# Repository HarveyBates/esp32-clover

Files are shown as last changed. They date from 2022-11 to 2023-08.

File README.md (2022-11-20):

# esp32-clover
ESP32 Clover development board.

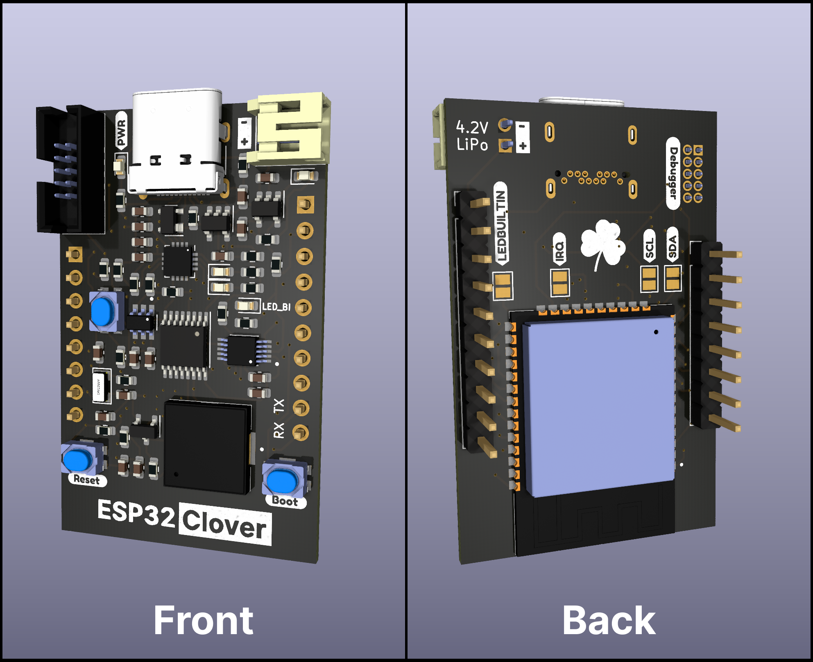
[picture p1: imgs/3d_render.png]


## Features
- [x] USB-C connector
- [x] Debugger connector for ESP-Prog
- [x] Piezo buzzer (audible feedback)
- [x] Additional ADC (2 inputs, 12-bit)
- [x] Additional IO (2 inputs/outputs with interrupt)
- [x] Additional DAC (1 channel, 8-bit)
- [x] Battery charger (single cell LiPo)
- [x] Built-in LED
- [x] Programmable button
- [x] Breadboard friendly
- [x] Small footprint (29.2 mm x 46.5 mm)

## Schematic
The devices schematic can be found [here](https://github.com/HarveyBates/esp32-clover/blob/master/electronics/esp32-clover/schematics/esp32-clover.pdf)

## Licence
This project is under the GNU LESSER GENERAL PUBLIC LICENSE as found in the LICENCE file.

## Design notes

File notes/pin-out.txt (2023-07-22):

GPIO - 8 (TCA9534 - 0 to 7)
PWR - 5 (USB, 3.3V, Bat, RESET, GND)
ADC - 5 (ADC124S... 0 to 3 GND)
DAC - 5 (MCP4728 0 to 3, GND)
MISC - 10 (TX, RX, SDA, SCL, SCK, MISO, MOSI, GPIO21, GPIO17, GPIO27)
	As two 5 Pins

1 x 8 pin
5 * 5 pin

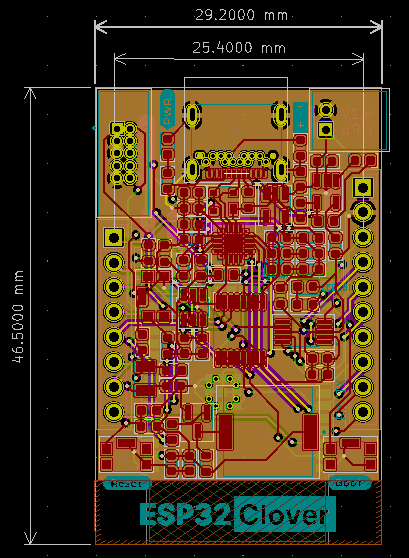
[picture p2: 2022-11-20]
imgs/pcb_layout.png

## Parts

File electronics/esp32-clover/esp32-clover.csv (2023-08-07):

Source: | /Users/hbates/projects/esp32-clover/electronics/esp32-clover/esp32-clover.kicad_sch
Date: | 2023 August 04, Friday 09:54:28
Tool: | Eeschema 7.0.6-0
Generator: | /Applications/KiCad/KiCad.app/Contents/SharedSupport/plugins/bom_csv_grouped_by_value.py
Component Count: | 136
Collated Components:
Item | Qty | Reference(s) | Value | LibPart | Footprint | Datasheet | DNP | Arrow Part Number | Arrow Price/Stock | Color | DESCRIPTION | DIGI-KEY_PART_NUMBER | DIGI-KEY_PURCHASE_URL | Height | MANUFACTURER | MAXIMUM_PACKAGE_HEIGHT | MP | Manufacturer_Name | Manufacturer_Part_Number | Mouser Part Number | Mouser Price/Stock | PACKAGE | PARTREV | Part | SNAPEDA_PN | STANDARD | Supplier
1 | 1 | BT1 | BCAAPC | BCAAPC:BCAAPC | BAT_BCAAPC |  |  |  |  |  |  |  |  |  | MPD | 13.25mm |  |  |  |  |  |  | 05/30/19 |  |  | Manufacturer Recommendation
2 | 4 | C1, C8, C29, C30 | 1uF | Device:C | Capacitor_SMD:C_0603_1608Metric | ~
3 | 5 | C2, C9, C11, C14, C15 | 0.1uF | Device:C | Capacitor_SMD:C_0603_1608Metric | ~
4 | 1 | C3 | 22uF | Device:C | Capacitor_SMD:C_0603_1608Metric | ~
5 | 4 | C4, C5, C6, C7 | 12pF | Device:C | Capacitor_SMD:C_0603_1608Metric | ~
6 | 1 | C10 | 10uF | Device:C | Capacitor_SMD:C_0603_1608Metric | ~
7 | 5 | C12, C13, C16, C18, C20 | 4.7uF | Device:C | Capacitor_SMD:C_0603_1608Metric | ~
8 | 1 | C17 | 2.2uF | Device:C |  | ~
9 | 3 | C19, C23, C24 | 1uF | Device:C |  | ~
10 | 2 | C21, C22 | 0.1uF | Device:C |  | ~
11 | 1 | C25 | 10uF | Device:C |  | ~
12 | 1 | C26 | 4.7uF | Device:C |  | ~
13 | 1 | C27 | 22pF | Device:C |  | ~
14 | 1 | C28 | TBD | Device:C | Capacitor_SMD:C_0603_1608Metric | ~ | DNP
15 | 4 | C31, C33, C34, C35 | 22uF | Device:C |  | ~
16 | 1 | C32 | 10nF | Device:C |  | ~
17 | 3 | D1, D2, D3 | SP4020-01FTG | SP4020-01FTG:SP4020-01FTG | SOD2613X114N | https://www.littelfuse.com/~/media/electronics/datasheets/tvs_diode_arrays/littelfuse_tvs_diode_array_sp4020_datasheet.pdf.pdf |  | SP4020-01FTG | https://www.arrow.com/en/products/sp4020-01ftg/littelfuse?region=nac |  |  |  |  | 1.14 |  |  |  | LITTELFUSE | SP4020-01FTG | 576-SP4020-01FTG | https://www.mouser.co.uk/ProductDetail/Littelfuse/SP4020-01FTG?qs=eIdvKxokjW4Yi6Ov7kZjPg%3D%3D
18 | 5 | D4, D5, D7, D8, D9 | LED | Device:LED | LED_SMD:LED_0603_1608Metric | ~ |  |  |  | Green
19 | 1 | D6 | SP0503BAHT | Power_Protection:SP0503BAHT | Package_TO_SOT_SMD:SOT-143 | http://www.littelfuse.com/~/media/files/littelfuse/technical%20resources/documents/data%20sheets/sp05xxba.pdf |  |  |  |  |  |  |  |  |  |  |  |  |  |  |  |  |  |  |  |  | https://au.element14.com/littelfuse/sp0503bahtg/esd-protection-device-5-5v-sot/dp/1827633?st=SP0503BAHTG
20 | 2 | D10, D11 | LED | Device:LED |  | ~
21 | 2 | D12, D13 | SK34A | diodes:SK34A | diodes:SK34A |  |  |  |  |  |  |  |  |  | Taiwan Semiconductor | 2.5 mm |  |  |  |  |  |  | O2102 |  |  | IPC-7351B
22 | 1 | D14 | D_Schottky | Device:D_Schottky |  | ~
23 | 9 | J1, J2, J3, J4, J6, J7, J8, J9, J10 | TBP02R2-381-05BE | TBP02R2-381-05BE:TBP02R2-381-05BE | CUI_TBP02R2-381-05BE |  |  |  |  |  |  |  |  |  | CUI |  |  |  |  |  |  |  |  |  |  | Manufacturer Recommendations
24 | 1 | J5 | Conn_ARM_JTAG_SWD_10 | Connector:Conn_ARM_JTAG_SWD_10 | jtag:3221-10-0100-00 | http://infocenter.arm.com/help/topic/com.arm.doc.ddi0314h/DDI0314H_coresight_components_trm.pdf
25 | 1 | J11 | USB4055-30-A | USB4055-30-A:USB4055-30-A | USB4055-30-A:USB4055-30-A |  |  |  |  |  | USB Type C Receptacle Horizontal Hybrid PCB Top Mount 10 mm Body | 2073-USB4055-30-ACT-ND | https://www.digikey.com.ua/product-detail/en/gct/USB4055-30-A/2073-USB4055-30-ACT-ND/9859729 |  | Global Connector Technology |  | USB4055-30-A |  |  |  |  | None | B |  |  | Manufacturer Recommendations | https://au.element14.com/gct-global-connector-technology/usb4055-30-a/usb-connector-3-1-type-c-rcpt/dp/2784982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
26 | 1 | J12 | ST1W008S4AR1500 | ST1W008S4AR1500:ST1W008S4AR1500 | JAE_ST1W008S4AR1500 |  |  |  |  |  |  |  |  |  | JAE Electronics | 2.0 mm |  |  |  |  |  |  | 2 |  |  | Manufacturer Recommendations
27 | 1 | L1 | 10uH | Device:L |  | ~ |  |  |  |  |  |  |  |  |  |  |  |  |  |  |  |  |  | ASPI-4030S-100M-T
28 | 1 | L2 | 1uH | Device:L |  | ~ |  |  |  |  |  |  |  |  |  |  |  |  |  |  |  |  |  | Similar to: XFL4020-102ME
29 | 1 | LS1 | PKMCS0909E4000-R1 | PKMCS0909E4000-R1:PKMCS0909E4000-R1 | SPKR_PKMCS0909E4000-R1 | https://www.murata.com/~/media/webrenewal/products/sound/sounder/vppt-buzj083-d.ashx |  |  |  |  |  |  |  |  | Murata Electronics | 1.9 mm |  |  |  |  |  |  | May 22, 2020 |  |  | Manufacturer Recommendations
30 | 1 | Q1 | BC847 | Transistor_BJT:BC847 | Package_TO_SOT_SMD:SOT-23 | http://www.infineon.com/dgdl/Infineon-BC847SERIES_BC848SERIES_BC849SERIES_BC850SERIES-DS-v01_01-en.pdf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
31 | 1 | Q2 | MMDT3904 | Transistor_BJT:MMDT3904 | Package_TO_SOT_SMD:SOT-363_SC-70-6 | http://www.diodes.com/_files/datasheets/ds30088.pdf
32 | 1 | Q3 | 2N7002 | Transistor_FET:2N7002 | Package_TO_SOT_SMD:SOT-23 | https://www.onsemi.com/pub/Collateral/NDS7002A-D.PDF
33 | 1 | Q4 | BSS214NW | Transistor_FET:BSS214NW | Package_TO_SOT_SMD:SOT-323_SC-70 | https://www.infineon.com/dgdl/Infineon-BSS214NW-DS-v02_02-en.pdf?fileId=db3a30431b3e89eb011b695aebc01bde
34 | 1 | Q5 | DMG2305UX-13 | DMG2305UX-13:DMG2305UX-13 | SOT91P240X110-3N |  |  |  |  |  |  |  |  |  | Diodes Inc. | 1.1mm |  |  |  |  |  |  | 09/2018 |  |  | IPC-7351B
35 | 7 | R1, R2, R4, R7, R9, R24, R25 | 10K | Device:R | Resistor_SMD:R_0603_1608Metric | ~
36 | 1 | R3 | 10M | Device:R | Resistor_SMD:R_0603_1608Metric | ~
37 | 4 | R5, R6, R11, R12 | 4.7K | Device:R | Resistor_SMD:R_0603_1608Metric | ~
38 | 5 | R8, R21, R22, R23, R29 | 1K | Device:R | Resistor_SMD:R_0603_1608Metric | ~
39 | 1 | R10 | 120 | Device:R |  | ~
40 | 2 | R13, R15 | 470 | Device:R | Resistor_SMD:R_0603_1608Metric | ~
41 | 2 | R14, R40 | 100K | Device:R | Resistor_SMD:R_0603_1608Metric | ~
42 | 2 | R16, R18 | 5.1K | Device:R | Resistor_SMD:R_0603_1608Metric | ~
43 | 1 | R17 | 1M | Device:R | Resistor_SMD:R_0603_1608Metric | ~
44 | 1 | R19 | 22.1K | Device:R | Resistor_SMD:R_0603_1608Metric | ~
45 | 1 | R20 | 47.5K | Device:R | Resistor_SMD:R_0603_1608Metric | ~
46 | 1 | R26 | 2 | Device:R |  | ~
47 | 1 | R27 | 82K | Device:R |  | ~
48 | 2 | R28, R38 | 20K | Device:R |  | ~
49 | 2 | R30, R31 | 500 | Device:R |  | ~
50 | 1 | R32 | 5.32K | Device:R |  | ~
51 | 1 | R33 | 30.1K | Device:R |  | ~
52 | 1 | R34 | 2.3K | Device:R | Resistor_SMD:R_0603_1608Metric | ~
53 | 1 | R35 | 10 | Device:R |  | ~
54 | 1 | R36 | 0.2 | Device:R |  | ~ |  |  |  |  |  |  |  |  |  |  |  |  |  |  |  |  |  | WSL1206R2000FEA
55 | 1 | R37 | 28K | Device:R |  | ~
56 | 2 | R39, R41 | 10K | Device:R |  | ~
57 | 1 | R42 | 402K | Device:R |  | ~
58 | 1 | R43 | 100K | Device:R |  | ~
59 | 3 | S1, S2, S3 | TL1105F160Q | TL1105F160Q:TL1105F160Q | SW_TL1105F160Q |  |  |  |  |  |  |  |  |  | E-Switch | 13 mm |  |  |  |  |  |  | A |  | TL1105DF160Q | Manufacturer Recommendations
60 | 1 | S4 | DS01-254-S-01BE | DS01-254-S-01BE:DS01-254-S-01BE | SW_DS01-254-S-01BE |  |  |  |  |  |  |  |  |  | CUI | 7.0mm |  |  |  |  |  |  | 1.0 |  |  | Manufacturer recommendations
61 | 1 | SC1 | Solar_Cell | Device:Solar_Cell |  | ~
62 | 1 | TH1 | ~ | Device:Thermistor |  | ~ |  |  |  |  |  |  |  |  |  |  |  |  |  |  |  |  |  | NXFT15XH103FEAB035
63 | 1 | U1 | ESP32-WROOM-32E_(16MB) | ESP32-WROOM-32E__16MB:ESP32-WROOM-32E_(16MB) | ESP32:ESP32-WROOM-32E__16MB |  |  |  |  |  |  |  |  |  | Espressif Systems | 3.25mm |  |  |  |  |  |  | 1.4 |  |  | Manufacturer Recommendations
64 | 1 | U2 | TXB0104PW | Logic_LevelTranslator:TXB0104PW | Package_SO:TSSOP-14_4.4x5mm_P0.65mm | http://www.ti.com/lit/ds/symlink/txb0104.pdf
65 | 1 | U3 | MCP2515-xSO | Interface_CAN_LIN:MCP2515-xSO | Package_SO:SOIC-18W_7.5x11.6mm_P1.27mm | http://ww1.microchip.com/downloads/en/DeviceDoc/21801e.pdf
66 | 1 | U4 | MCP2562-E-SN | Interface_CAN_LIN:MCP2562-E-SN | Package_SO:SOIC-8_3.9x4.9mm_P1.27mm | http://ww1.microchip.com/downloads/en/DeviceDoc/25167A.pdf
67 | 1 | U5 | ADC124S101CIMM | ADC124S101CIMM:ADC124S101CIMM | SOP50P490X110-10N | https://www.ti.com/lit/ds/symlink/adc124s101.pdf?HQS=dis-dk-null-digikeymode-dsf-pf-null-wwe&ts=1668772001635 |  |  |  |  |  |  |  |  |  |  |  |  |  |  |  |  |  |  |  |  | https://www.digikey.com.au/en/products/detail/texas-instruments/ADC124S101CIMM-NOPB/755015
68 | 2 | U6, U7 | TCA9534 | Interface_Expansion:TCA9534 | Package_SO:TSSOP-16_4.4x5mm_P0.65mm | http://www.ti.com/lit/ds/symlink/tca9534.pdf
69 | 1 | U8 | MCP4728 | Analog_DAC:MCP4728 | Package_SO:MSOP-10_3x3mm_P0.5mm | http://ww1.microchip.com/downloads/en/DeviceDoc/22187E.pdf
70 | 1 | U9 | CP2102N-Axx-xQFN20 | Interface_USB:CP2102N-Axx-xQFN20 | Package_DFN_QFN:SiliconLabs_QFN-20-1EP_3x3mm_P0.5mm_EP1.8x1.8mm | https://www.silabs.com/documents/public/data-sheets/cp2102n-datasheet.pdf |  |  |  |  |  |  |  |  |  |  |  |  |  |  |  |  |  |  |  |  | https://au.element14.com/silicon-labs/cp2102n-a02-gqfn20r/usb-uart-bridge-40-to-85deg-c/dp/3387001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
71 | 1 | U10 | MCP73123T-22SI/MF | MCP73123T-22SI_MF:MCP73123T-22SI{slash}MF | SON50P300X300X100-11N |  |  |  |  |  |  |  |  |  | MICROCHIP
72 | 1 | U11 | BQ24650RVAR | solar-charger:BQ24650RVAR | solar-charger:BQ24650RVAR
73 | 2 | U12, U13 | PMV30UN | mosfets:PMV30UN | mosfets:PMV30UN | PMV30UN
74 | 1 | U14 | NCP163ASN330T1G | Regulator_Linear:NCP163ASN330T1G | Package_TO_SOT_SMD:SOT-23-5 | https://www.onsemi.com/pdf/datasheet/ncp163-d.pdf
75 | 1 | U15 | TPS61230DRC | Regulator_Switching:TPS61230DRC | Package_SON:Texas_S-PVSON-N10_ThermalVias | http://www.ti.com/lit/ds/symlink/tps61232.pdf
76 | 1 | Y1 | ABS07AIG-32.768KHZ-T | ABS07AIG-32.768KHZ-T:ABS07AIG-32.768KHZ-T | XTAL320X150X90
77 | 1 | Y2 | Crystal_GND24_Small | Device:Crystal_GND24_Small |  | ~

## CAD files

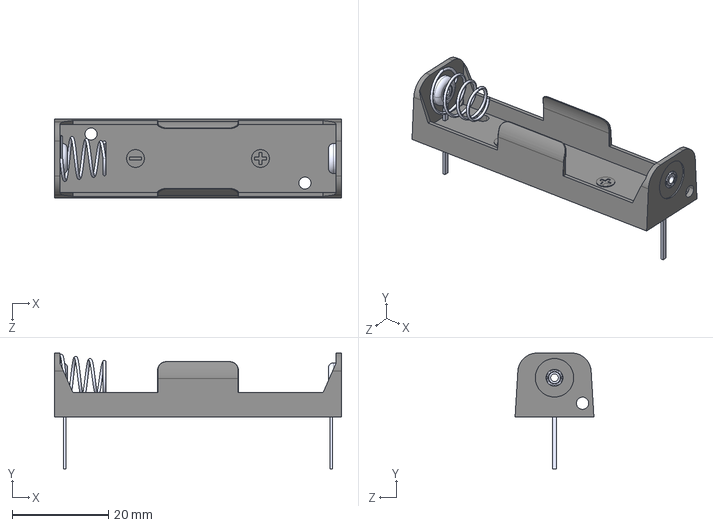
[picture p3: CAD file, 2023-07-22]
electronics/esp32-clover/components/extern/3dmodels/battery_holders/BCAAPC.step
59.7 x 24.1 x 16.4 mm

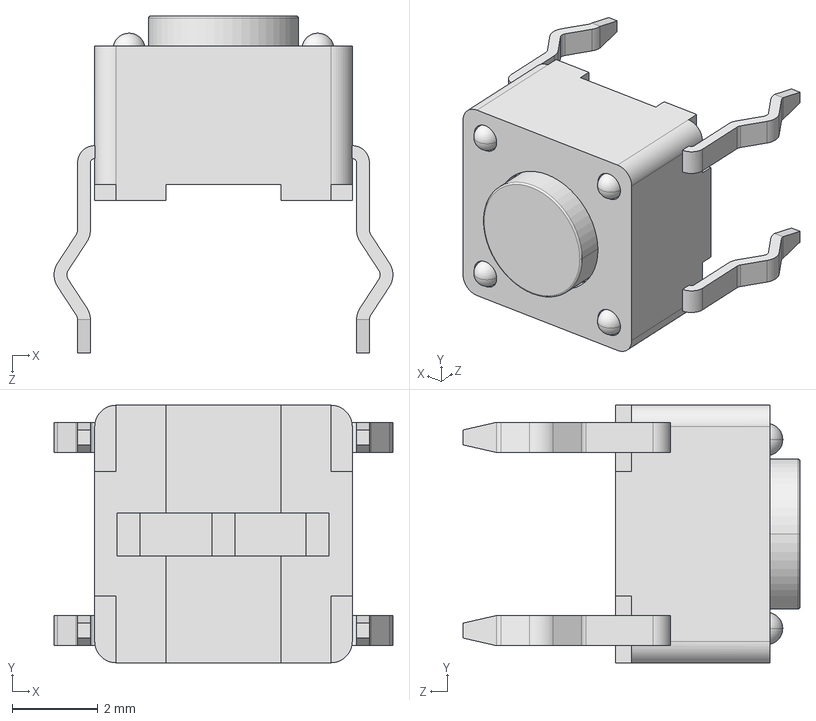
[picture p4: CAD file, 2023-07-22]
electronics/esp32-clover/components/extern/3dmodels/buttons/TL1105F160Q.step
7.89 x 6.00 x 7.85 mm

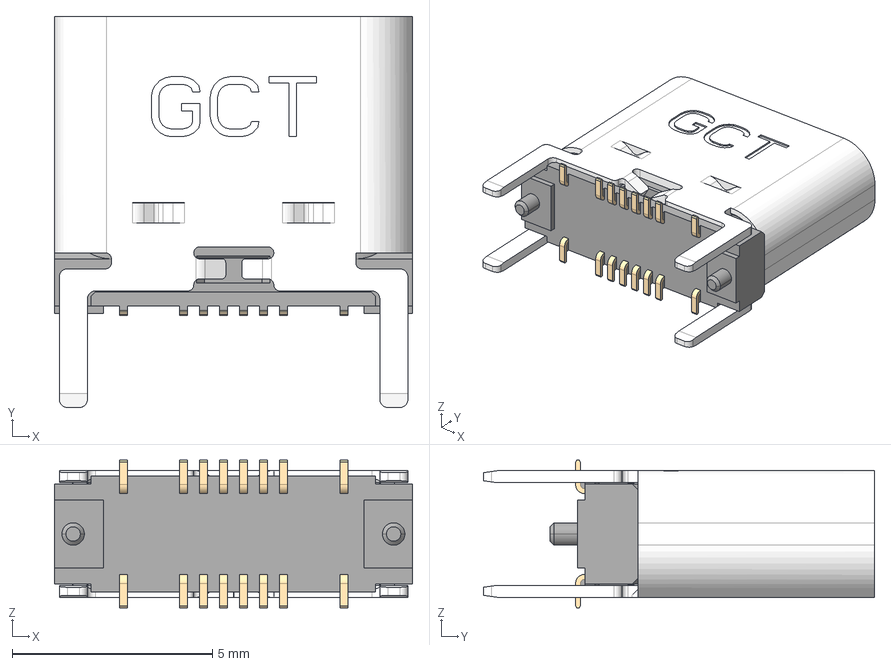
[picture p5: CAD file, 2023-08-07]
electronics/esp32-clover/components/extern/3dmodels/connectors_usb/USB4145-03-0230-C_REVA2.step
8.95 x 9.76 x 3.69 mm

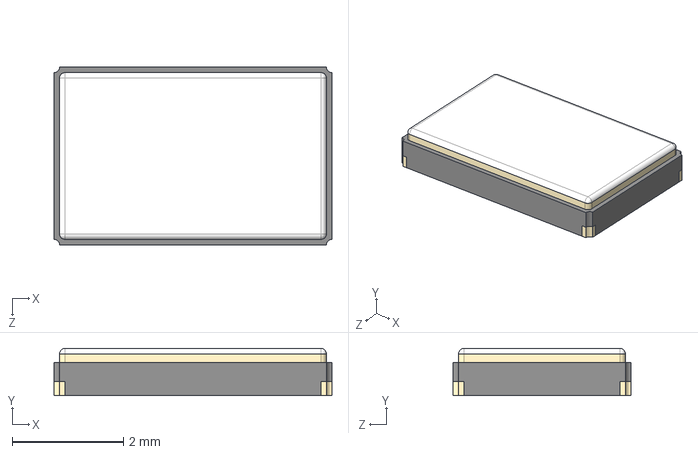
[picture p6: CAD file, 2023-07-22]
electronics/esp32-clover/components/extern/3dmodels/crystals/ECS-160-8-30B-CKM.step
5.00 x 0.85 x 3.20 mm

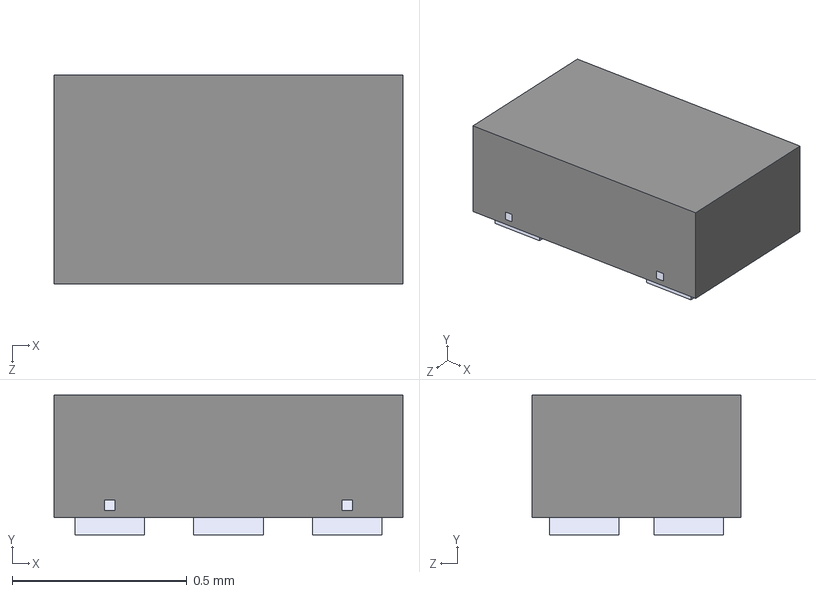
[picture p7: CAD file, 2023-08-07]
electronics/esp32-clover/components/extern/3dmodels/diodes_esd/ESD122DMXR.step
1.00 x 0.4 x 0.6 mm

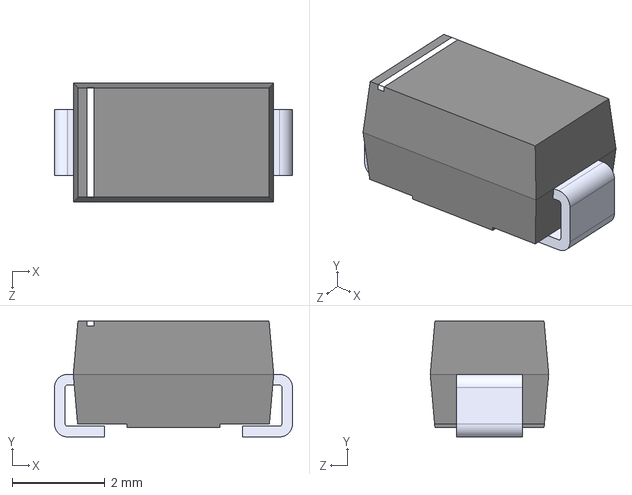
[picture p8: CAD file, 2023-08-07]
electronics/esp32-clover/components/extern/3dmodels/diodes_schottky/SK34A.step
5.14 x 2.50 x 2.56 mm

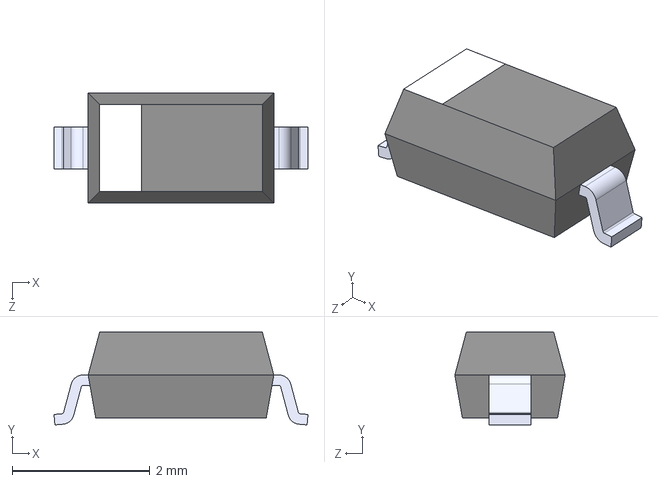
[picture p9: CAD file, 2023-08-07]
electronics/esp32-clover/components/extern/3dmodels/diodes_zener/MMSZ4700T1G.step
3.68 x 1.35 x 1.60 mm

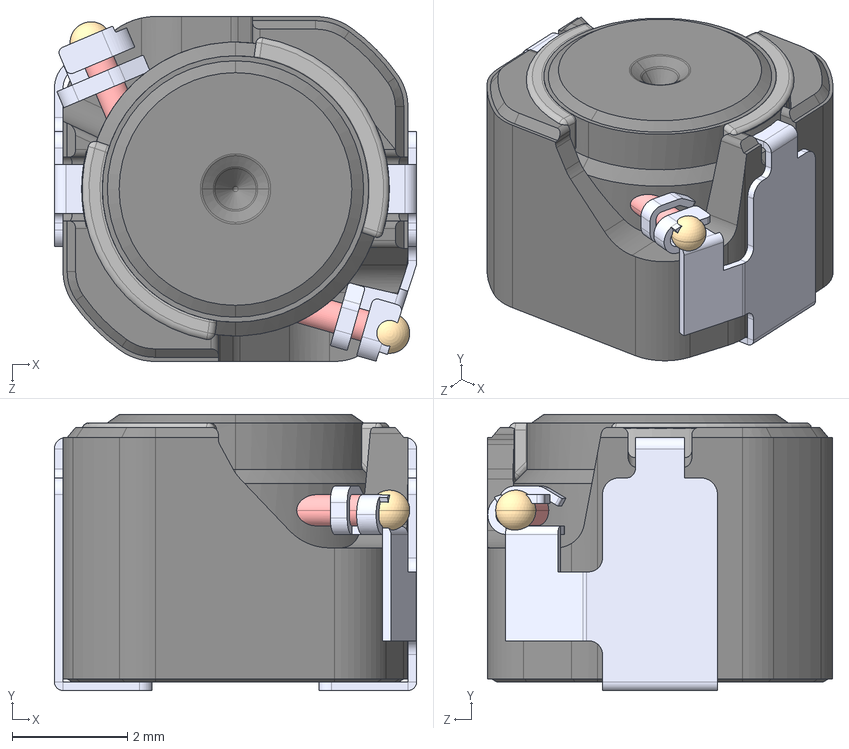
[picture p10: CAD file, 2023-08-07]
electronics/esp32-clover/components/extern/3dmodels/inductors/CLF6045NIT-470M-D.step
6.30 x 4.80 x 6.00 mm

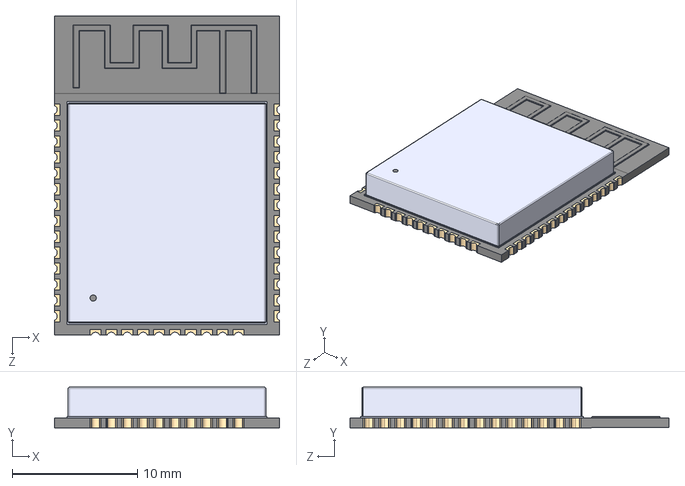
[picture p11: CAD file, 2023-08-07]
electronics/esp32-clover/components/extern/3dmodels/microcontrollers/ESP32-WROOM-32E_16MB.step
18.0 x 3.25 x 25.5 mm

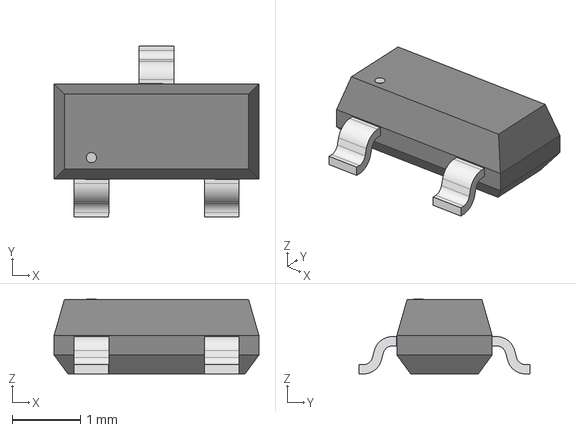
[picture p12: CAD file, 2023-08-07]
electronics/esp32-clover/components/extern/3dmodels/mosfets/PMV30UN.step
3.00 x 2.50 x 1.09 mm

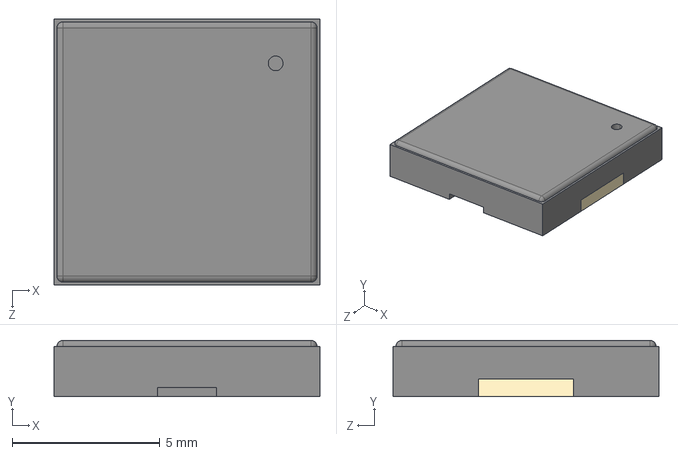
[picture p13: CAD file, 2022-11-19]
electronics/esp32-clover/components/extern/3dmodels/piezo_buzzers/PKMCS0909E4000-R1.step
9.00 x 1.90 x 9.00 mm

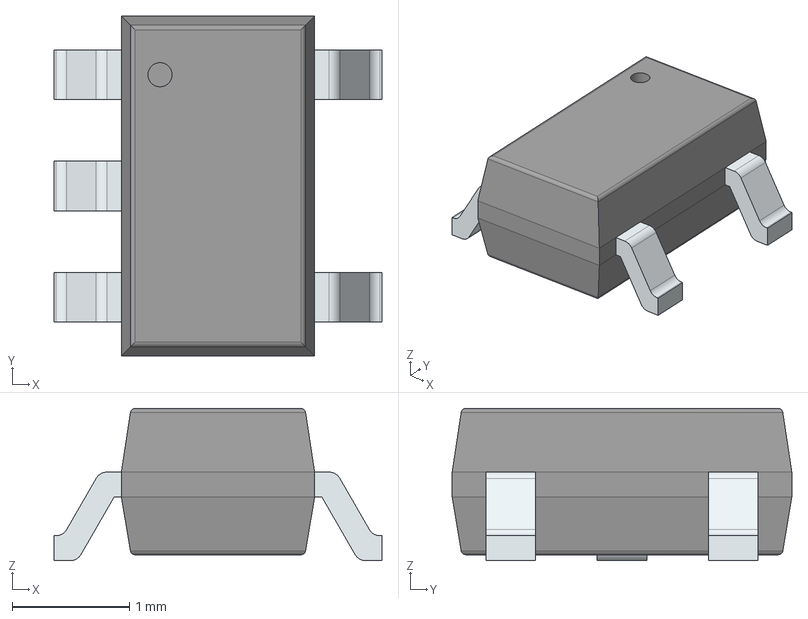
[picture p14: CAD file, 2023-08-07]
electronics/esp32-clover/components/extern/3dmodels/voltage_regs/XC6215B332MR-G.stp
2.80 x 2.90 x 1.30 mm
PinsArrayL
PinsArrayR

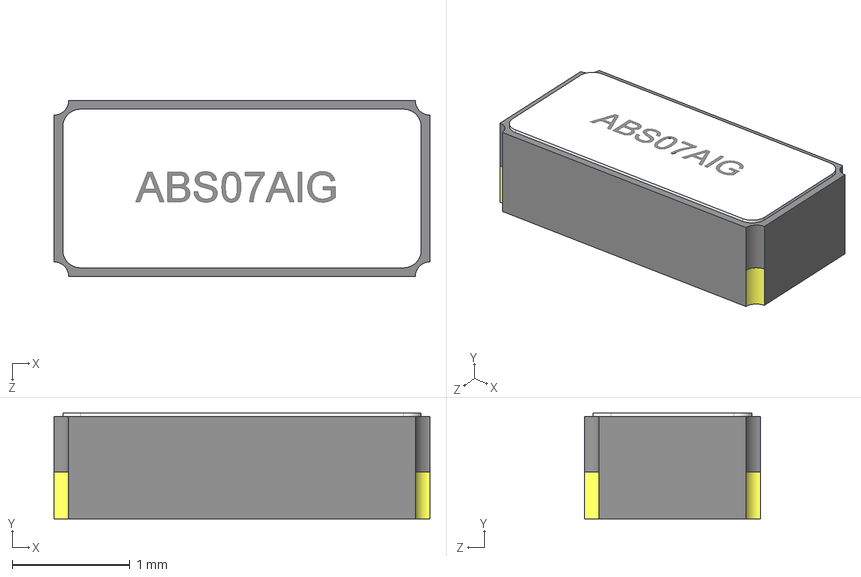
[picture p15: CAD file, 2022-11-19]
electronics/esp32-clover/components/extern/tmp/ABS07AIG-32.768KHZ-T/ABS07AIG-32.768KHZ-T.step
3.20 x 0.901 x 1.50 mm

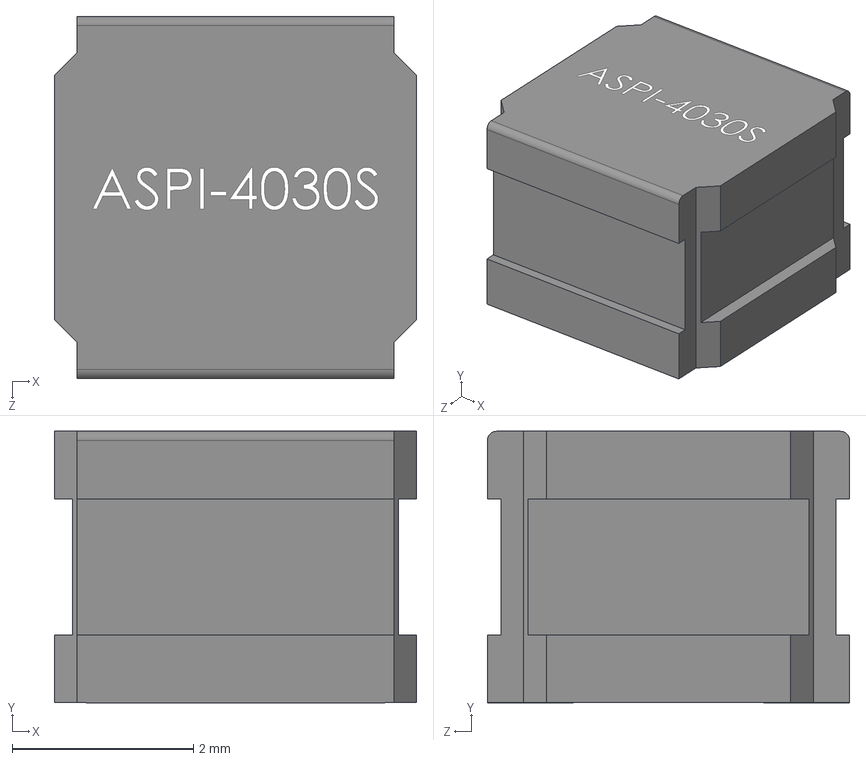
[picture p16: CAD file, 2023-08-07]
electronics/esp32-clover/components/extern/tmp/ASPI-4030S-100M-T/ASPI-4030S-100M-T.step
4.00 x 3.00 x 4.00 mm

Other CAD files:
electronics/esp32-clover/components/extern/3dmodels/battery_chargers/MCP73123T-22SI_MF.step
electronics/esp32-clover/components/extern/3dmodels/mosfets/ZXMP7A17KTC.step
electronics/esp32-clover/components/extern/3dmodels/solar_chargers/BQ24650RVAR.step
electronics/esp32-clover/components/extern/tmp/BQ24650RVAR/BQ24650RVAR.step
electronics/esp32-clover/components/extern/tmp/MCP73123T-22SI_MF/MCP73123T-22SI_MF.step
electronics/esp32-clover/components/extern/tmp/XC6215B332MR-G/XC6215B332MR-G/Allegro/sot95p280x130-5n.psm
electronics/esp32-clover/components/extern/tmp/XC6215B332MR-G/XC6215B332MR-G/DEHDL/xc6215b332mr_g/chips/chips.prt
electronics/esp32-clover/components/extern/tmp/ZXMP7A17KTC/TO-252-3_6P6X6P1_DIO.step

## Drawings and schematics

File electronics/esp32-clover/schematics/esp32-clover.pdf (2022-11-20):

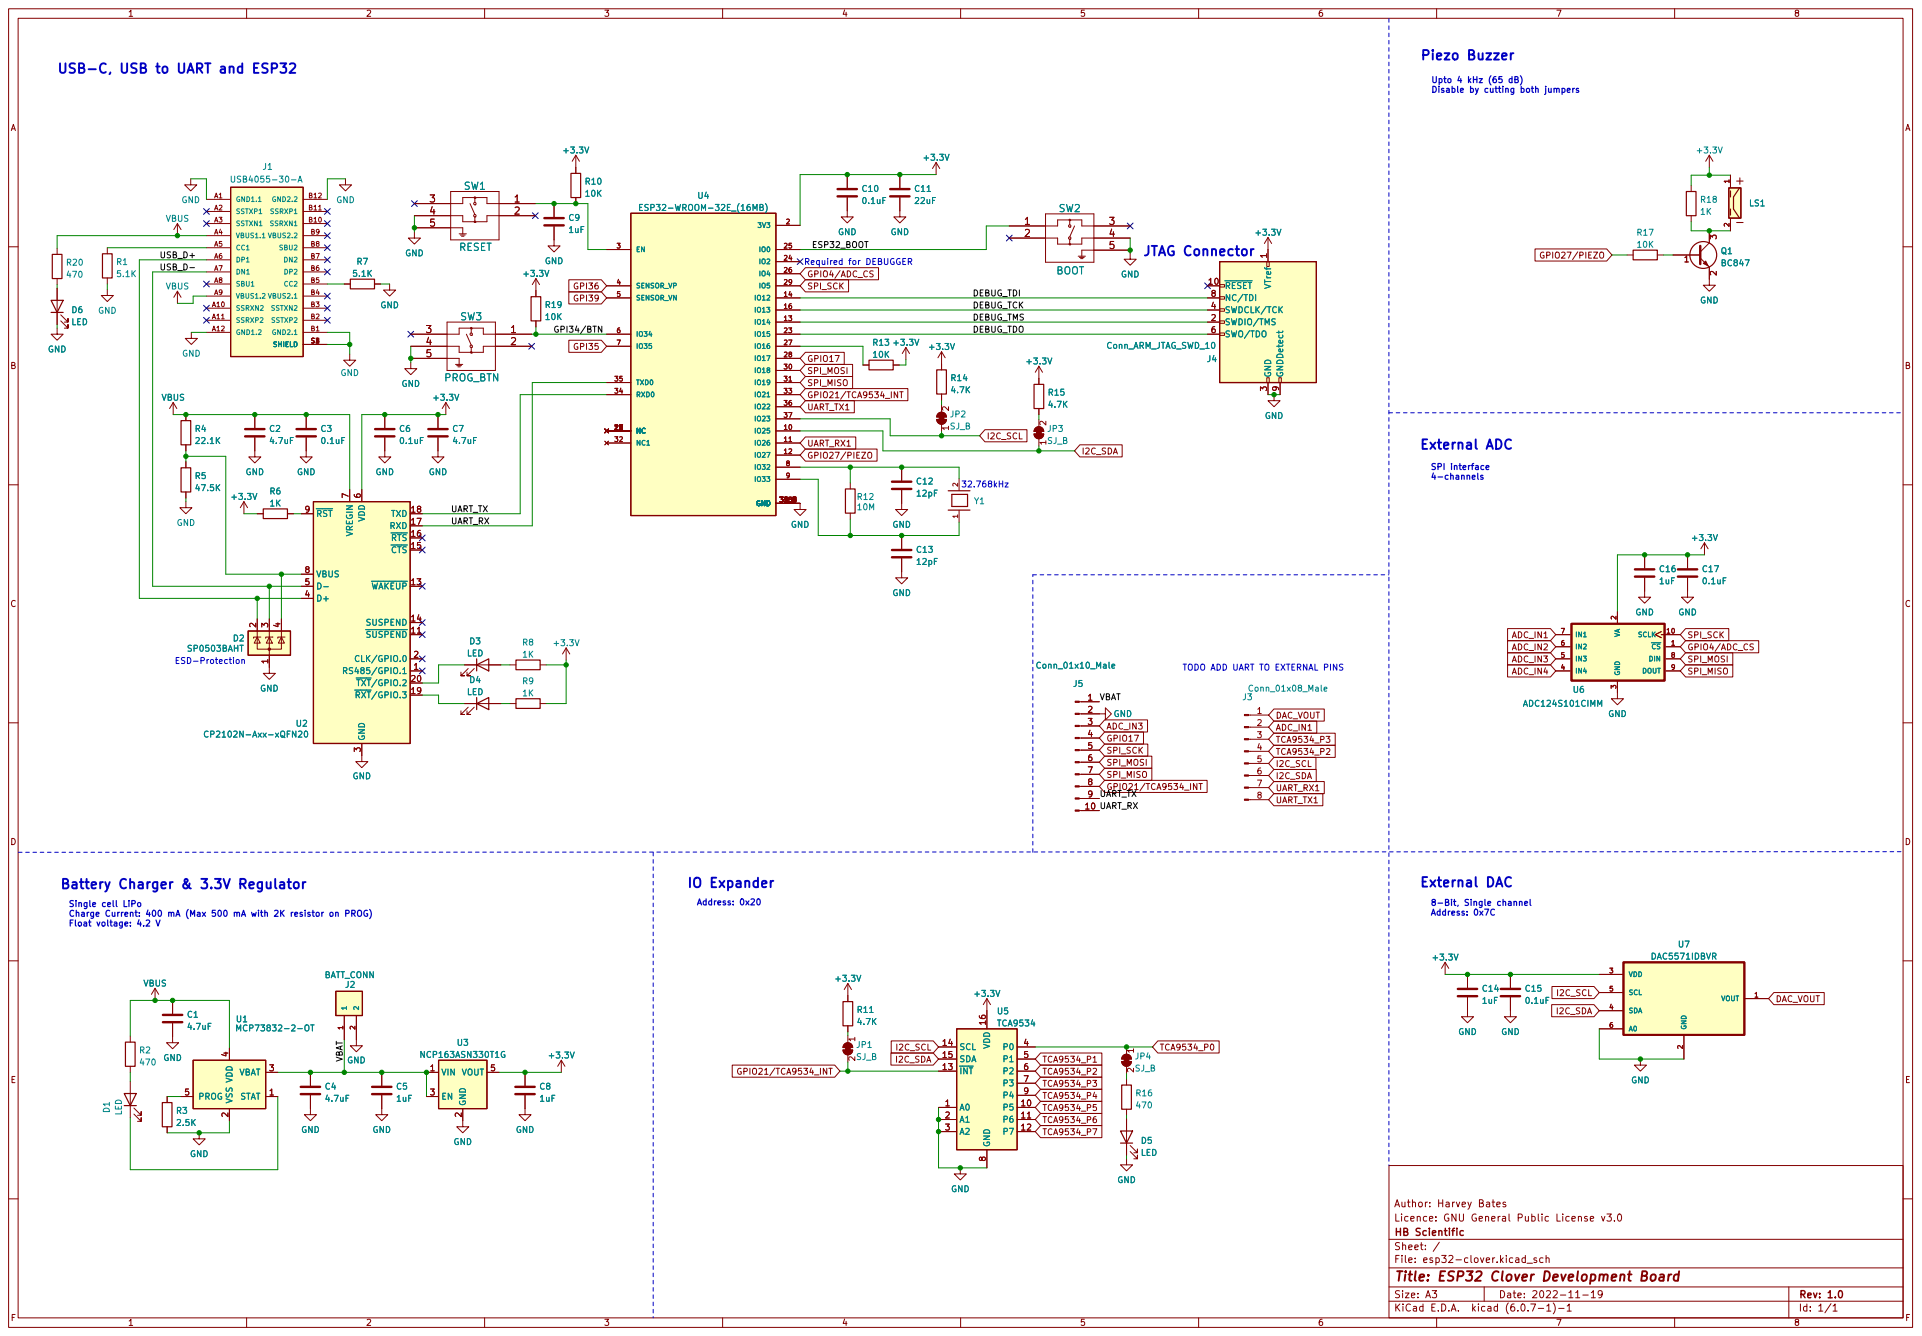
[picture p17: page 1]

Piezo Buzzer
4-channels Upto 4 kHz (65 dB)
Disable by cutting both jumpers

TODO ADD UART TO EXTERNAL PINS USB-C, USB to UART and ESP32

3 SWDCLK/TCK 4 SWO/TDO 6 NC/TDI 8 GNDDetect 9 GND GND

3 SWDCLK/TCK 4 SWO/TDO 6 NC/TDI 8 GNDDetect 9

Single cell LiPo
Charge Current: 400 mA (Max 500 mA with 2K resistor on PROG)
Float voltage: 4.2 V

8-Bit, Single channel Address: 0x7C

2 VDD 3 SDA 4 SCL 5 A0 6 U7 DAC5571IDBVR GND

2 VDD 3 SDA 4 SCL 5 A0 6 GND

Licence: GNU General Public License v3.0 Author: Harvey Bates C8

File: esp32-clover.kicad_sch Sheet: / HB Scientific

Id: 1/1 Title: ESP32 Clover Development Board

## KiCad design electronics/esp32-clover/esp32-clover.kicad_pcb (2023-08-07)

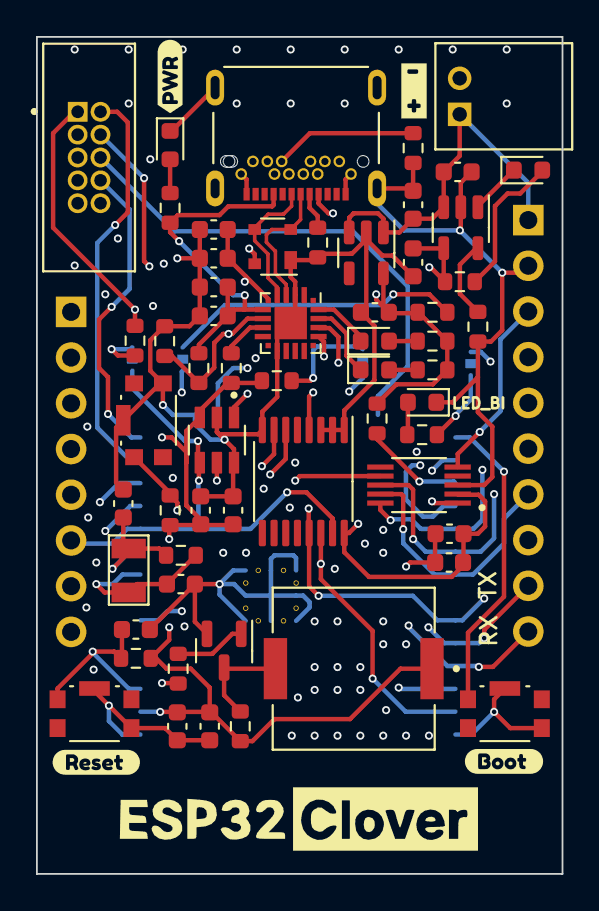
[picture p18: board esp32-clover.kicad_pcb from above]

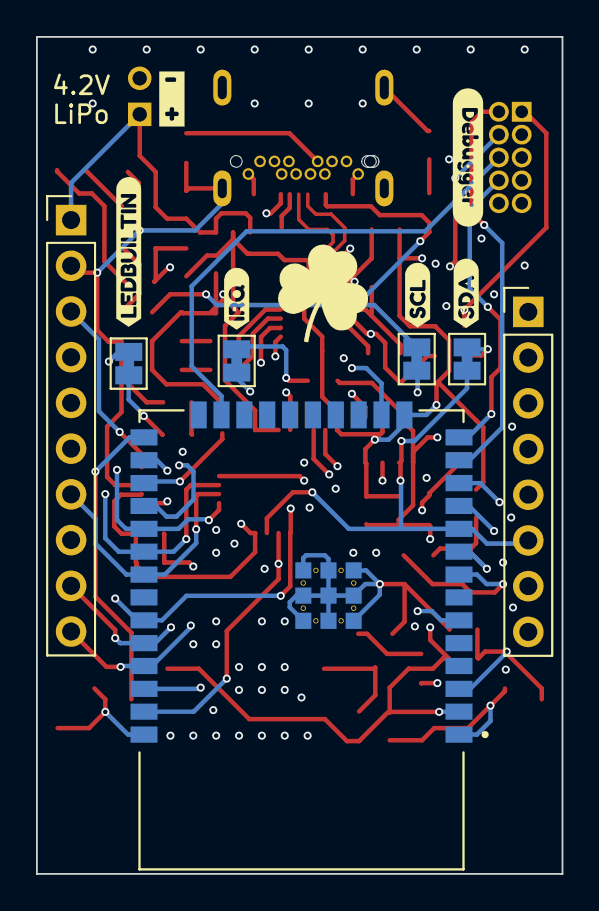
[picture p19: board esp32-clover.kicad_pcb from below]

Board: 4 copper layers, 29.2 x 46.5 mm, 75 parts (13 on the bottom side), 54 nets.

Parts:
C1, C2, C4, C7: 4.7uF; C_0603_1608Metric
C3, C6, C10, C15, C17: 0.1uF; C_0603_1608Metric
C5, C8, C9, C14, C16: 1uF; C_0603_1608Metric
C11: 22uF; C_0603_1608Metric
C12, C13: 12pF; C_0603_1608Metric
D1, D3, D4, D5, D6: LED; LED_0603_1608Metric
D2: SP0503BAHT; SOT-143
J1: USB4055-30-A
J2: BATT_CONN; S2B-PH-K-S_LF__SN
J3: Conn_01x08_Male; PinHeader_1x08_P2.54mm_Vertical
J4: Conn_ARM_JTAG_SWD_10; 3221-10-0100-00
J5: Conn_01x10_Male; PinHeader_1x10_P2.54mm_Vertical
JP1, JP2, JP3, JP4: SJ_B; SolderJumper-2_P1.3mm_Bridged_Pad1.0x1.5mm
LS1: PKMCS0909E4000-R1
Q1: BC847; SOT-23
R1, R7: 5.1K; R_0603_1608Metric
R2, R16, R20: 470; R_0603_1608Metric
R3: 2.5K; R_0603_1608Metric
R4: 22.1K; R_0603_1608Metric
R5: 47.5K; R_0603_1608Metric
R6, R8, R9, R18: 1K; R_0603_1608Metric
R10, R13, R17, R19: 10K; R_0603_1608Metric
R11, R14, R15: 4.7K; R_0603_1608Metric
R12: 10M; R_0603_1608Metric
SW1: RESET; MCIPTG23K-V
SW2: BOOT; MCIPTG23K-V
SW3: PROG_BTN; MCIPTG23K-V
U1: MCP73832-2-OT; SOT-23-5
U2: CP2102N-Axx-xQFN20; SiliconLabs_QFN-20-1EP_3x3mm_P0.5mm_EP1.8x1.8mm
U3: NCP163ASN330T1G; SOT-23-5
U4: ESP32-WROOM-32E_(16MB); ESP32-WROOM-32E__16MB
U5: TCA9534; TSSOP-16_4.4x5mm_P0.65mm
U6: ADC124S101CIMM
U7: DAC5571IDBVR; SOT95P280X145-6N
Y1: ABS07AIG-32.768KHZ-T
kibuzzard-6379A8C6: G***; kibuzzard-6379A8C6
kibuzzard-6379A9B5: G***; kibuzzard-6379A9B5
kibuzzard-6379A92C: G***; kibuzzard-6379A92C
kibuzzard-6379A99C: G***; kibuzzard-6379A99C
kibuzzard-6379A982: G***; kibuzzard-6379A982
kibuzzard-6379AA22: G***; kibuzzard-6379AA22
kibuzzard-6379AA41: G***; kibuzzard-6379AA41
kibuzzard-6379AB75, kibuzzard-6379AB75#2: G***; kibuzzard-6379AB75
kibuzzard-6379ABD3: G***; kibuzzard-6379ABD3

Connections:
+3.3V: C6.1, C7.1, C8.1, C10.1, C11.1, C14.1, C15.1, C16.1, C17.1, J4.1 (VTref), LS1.1, R6.2, R8.1, R9.1, R10.2, R11.2, R13.2, R14.2, R15.2, R18.2, R19.2, U2.6 (VDD), U3.5 (VOUT), U4.2 (3V3), U5.16 (VDD), U6.2 (VA), U7.3 (VDD)
/DEBUG_TCK: J4.4 (SWDCLK/TCK), U4.16 (IO13)
/DEBUG_TDI: J4.8 (NC/TDI), U4.14 (IO12)
/DEBUG_TDO: J4.6 (SWO/TDO), U4.23 (IO15)
/DEBUG_TMS: J4.2 (SWDIO/TMS), U4.13 (IO14)
/ESP32_BOOT: SW2.1, U4.25 (IO0)
/GPI34/BTN: R19.1, SW3.1, U4.6 (IO34)
/UART_RX: J5.10, U2.17 (RXD), U4.35 (TXD0)
/UART_TX: J5.9, U2.18 (TXD), U4.34 (RXD0)
/USB_D+: D2.2 (K), J1.A6 (DP1), U2.4 (D+)
/USB_D-: D2.3 (K), J1.A7 (DN1), U2.5 (D-)
/VBAT: C4.1, C5.1, J2.1, J5.1, U1.3 (VBAT), U3.1 (VIN), U3.3 (EN)
ADC_IN1: J3.2, U6.7 (IN1)
ADC_IN3: J5.3, U6.5 (IN3)
DAC_VOUT: J3.1, U7.1 (VOUT)
GND: C1.2, C2.2, C3.2, C4.2, C5.2, C6.2, C7.2, C8.2, C9.2, C10.2, C11.2, C12.2, C13.2, C14.2, C15.2, C16.2, C17.2, D2.1 (A), D5.1 (K), D6.1 (K), J1.A1 (GND1.1), J1.A12 (GND1.2), J1.B1 (GND2.1), J1.B12 (GND2.2), J1.S1 (SHIELD), J1.S2 (SHIELD), J1.S3 (SHIELD), J1.S4 (SHIELD), J2.2, J4.3 (GND), J4.5 (GND), J4.9 (GNDDetect), J5.2, Q1.2 (E), R1.1, R3.1, R5.2, R7.2, SW1.4, SW1.5, SW2.4, SW2.5, SW3.4, SW3.5, U1.2 (VSS), U2.3 (GND), U2.12 (GND), U2.21 (GND), U3.2 (GND), U4.1 (GND), U4.15 (GND), U4.38 (GND), U4.39_1 (GND), U4.39_2 (GND), U4.39_3 (GND), U4.39_4 (GND), U4.39_5 (GND), U4.39_6 (GND), U4.39_7 (GND), U4.39_8 (GND), U4.39_9 (GND), U5.1 (A0), U5.2 (A1), U5.3 (A2), U5.8 (GND), U6.3 (GND), U7.2 (GND), U7.6 (A0)
GPIO4/ADC_CS: U4.26 (IO4), U6.1 (~CS)
GPIO17: J5.4, U4.28 (IO17)
GPIO21/TCA9534_INT: J5.8, JP1.2 (B), U4.33 (IO21), U5.13 (~INT)
GPIO27/PIEZO: R17.2, U4.12 (IO27)
I2C_SCL: J3.5, JP2.1 (A), U4.37 (IO23), U5.14 (SCL), U7.5 (SCL)
I2C_SDA: J3.6, JP3.1 (A), U4.10 (IO25), U5.15 (SDA), U7.4 (SDA)
unnamed: C9.1, R10.1, SW1.1, U4.3 (EN)
unnamed: C12.1, R12.2, U4.8 (IO32), Y1.2
unnamed: C13.1, R12.1, U4.9 (IO33), Y1.1
unnamed: D1.1 (K), U1.1 (STAT)
unnamed: D1.2 (A), R2.2
unnamed: D2.4 (K), R4.2, R5.1, U2.8 (VBUS)
unnamed: D3.1 (K), U2.20 (~TXT/GPIO.2)
unnamed: D3.2 (A), R8.2
unnamed: D4.1 (K), U2.19 (~RXT/GPIO.3)
unnamed: D4.2 (A), R9.2
unnamed: D5.2 (A), R16.1
unnamed: D6.2 (A), R20.1
unnamed: J1.A5 (CC1), R1.2
unnamed: J1.B5 (CC2), R7.1
unnamed: JP1.1 (A), R11.1
unnamed: JP2.2 (B), R14.1
unnamed: JP3.2 (B), R15.1
unnamed: JP4.2 (B), R16.2
unnamed: LS1.2, Q1.3 (C), R18.1
unnamed: Q1.1 (B), R17.1
unnamed: R3.2, U1.5 (PROG)
unnamed: R6.1, U2.9 (~RST)
unnamed: R13.1, U4.27 (IO16)
SPI_MISO: J5.7, U4.31 (IO19), U6.9 (DOUT)
SPI_MOSI: J5.6, U4.30 (IO18), U6.8 (DIN)
SPI_SCK: J5.5, U4.29 (IO5), U6.10 (SCLK)
TCA9534_P0: JP4.1 (A), U5.4 (P0)
TCA9534_P2: J3.4, U5.6 (P2)
TCA9534_P3: J3.3, U5.7 (P3)
UART_RX1: J3.7, U4.11 (IO26)
UART_TX1: J3.8, U4.36 (IO22)
VBUS: C1.1, C2.1, C3.1, J1.A4 (VBUS1.1), J1.A9 (VBUS1.2), R2.1, R4.1, R20.2, U1.4 (VDD), U2.7 (VREGIN)

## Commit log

2022-11-19 initial commit of electronics
    [ABS07AIG-32.768KHZ-T.step, ADC124S101CIMM.step, DAC5571IDBVR.step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]
2022-11-19 added boards json configuration
2022-11-20 added pcb layout and imgs folder
    [3221-10-0100-00.STEP, CP2102N-A02-GQFN20R.step, PTS810 SJK 250 SMTR LFS.step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]
2022-11-20 added transfer and stitching vias, closes #1
    [esp32-clover.kicad_pcb]
2022-11-20 added gerber and sent first version off to be manufactured (v0.1)
    [esp32-clover-B_Cu.gbr, esp32-clover-B_Mask.gbr, esp32-clover-B_Paste.gbr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]
2022-11-20 added schematic for v0.1
2022-12-19 added arduino variant pin definitions, still more to do
    [esp32-clover.csv, esp32-clover.kicad_sch]
2023-07-09 update for v0.2
    [DMG2305UX-13.step, esp32-clover.kicad_sch]
2023-07-22 update for v2
    [BCAAPC.step, ECS-160-8-30B-CKM.step, MCP73123T-22SI_MF.step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]
2023-08-07 update before switching to stm32
    [3221-10-0100-00.STEP, ABS07AIG-32.768KHZ-T.step, ADC124S101CIMM.step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]

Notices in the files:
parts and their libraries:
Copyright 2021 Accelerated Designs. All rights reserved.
